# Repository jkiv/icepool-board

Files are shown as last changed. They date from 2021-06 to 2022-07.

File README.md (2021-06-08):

icepool-board
=============

KiCad 5 design files for the `icepool` project.

`icepool` is a FPGA cluster and development board.

Key features include,

- 16x headers for daughter boards.
- An FT2232H for USB communication and parallel FPGA flashing.
- One-to-many SPI interface for sending data from the PC to each daughter board.
- Daisy-chained SPI interface for passing data to and from the PC and each daughter board.
- A 6-pin ATX +12V power connector for use with conventional PC power supplies.

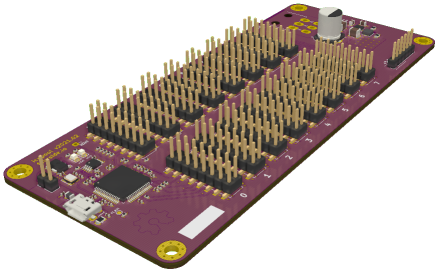
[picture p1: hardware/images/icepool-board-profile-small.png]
icepool-board - 3D Render


Currently, the project includes a daughter board design featuring a single [ice40hx8k-bg121](http://www.latticesemi.com/iCE40) FPGA with independent 1.2V LDO, 12MHz oscillator, and indicator LED.

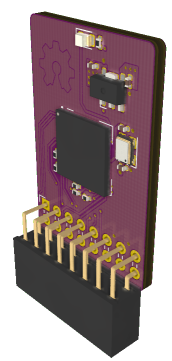
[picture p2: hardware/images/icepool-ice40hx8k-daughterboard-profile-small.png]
ice40hx8k bg121 daughter board - 3D render


## Dependencies

This project depends on the following KiCad libraries:

* [Digi-Key/digikey-kicad-library](https://github.com/Digi-Key/digikey-kicad-library)
* [jkiv/jkiv-kicad-library](https://github.com/jkiv/jkiv-kicad-library)

These repositories are set up as git submodules and can be cloned into `hardware/external/` using the following two commands:

    $ git submodule init
    $ git submodule update

## Drivers

See [jkiv/icepool-driver](https://github.com/jkiv/icepool-driver) project for a general-purpose Linux C library with Python3 bindings.

## Cores

* [jkiv/shapool-core](https://github.com/jkiv/shapool-core) - a SHA256d hashing core for cryptocurrency mining.

## Donate

Please consider supporting this project and others like it by donating:

* ☕: [ko-fi.com/jkiv_](https://ko-fi.com/jkiv_)
* ₿: `13zRrs1YDdooUN5WtfXRSDn8KnJdok4qG9`

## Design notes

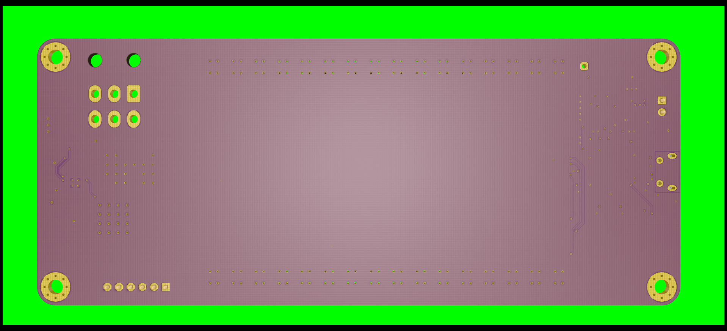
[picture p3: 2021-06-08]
hardware/images/icepool-board_bottom.png

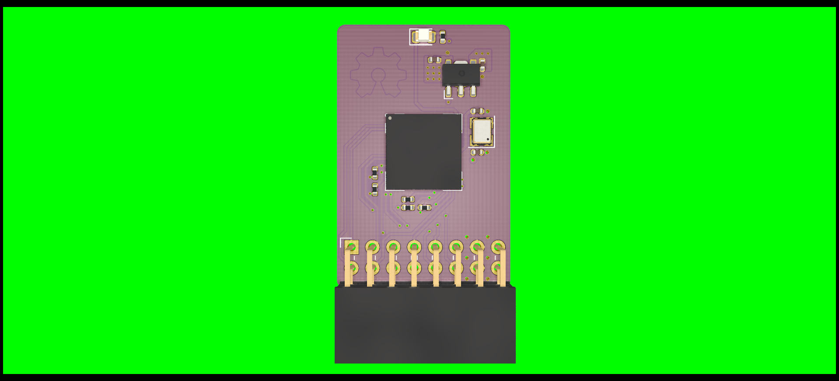
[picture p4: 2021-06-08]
hardware/images/icepool-ice40hx8k-daughterboard-top.png

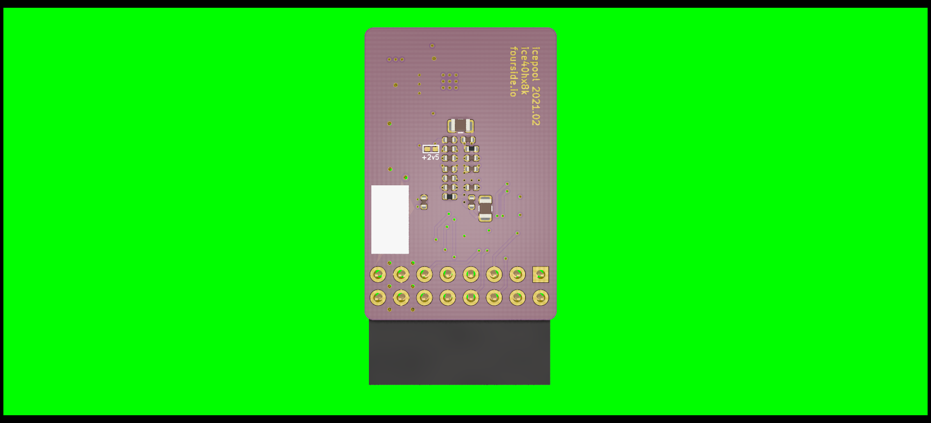
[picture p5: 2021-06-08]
hardware/images/icepool-ice40hx8k-daughterboard-bottom.png

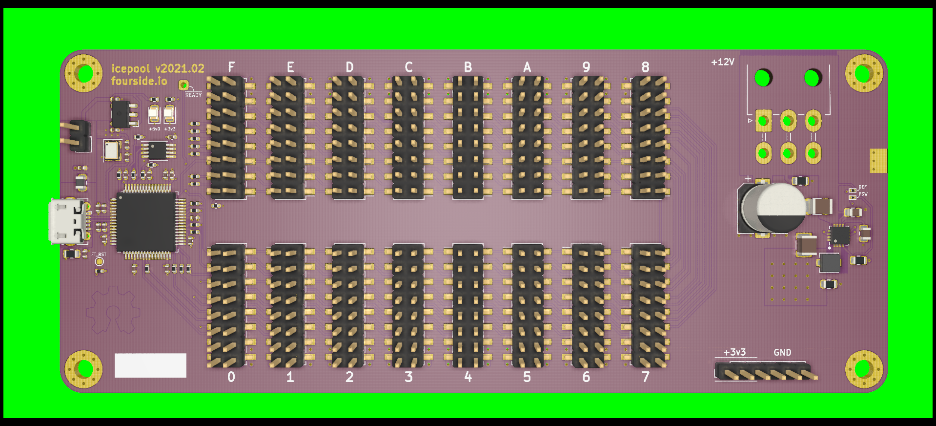
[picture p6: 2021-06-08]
hardware/images/icepool-board_top.png

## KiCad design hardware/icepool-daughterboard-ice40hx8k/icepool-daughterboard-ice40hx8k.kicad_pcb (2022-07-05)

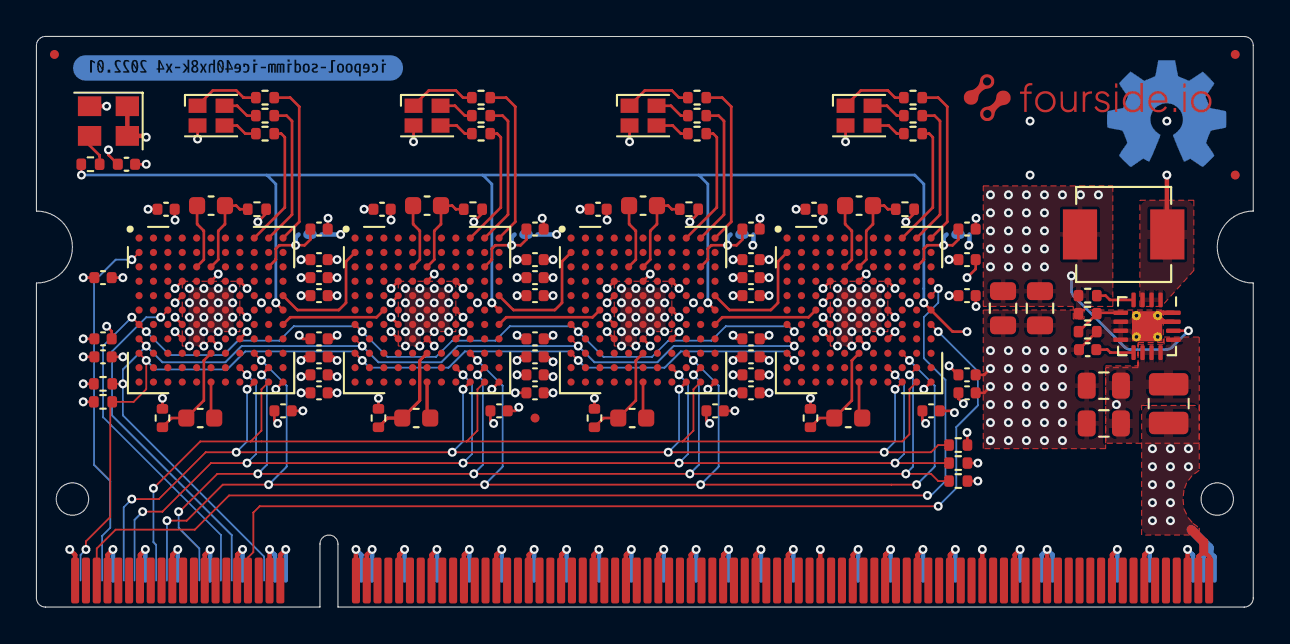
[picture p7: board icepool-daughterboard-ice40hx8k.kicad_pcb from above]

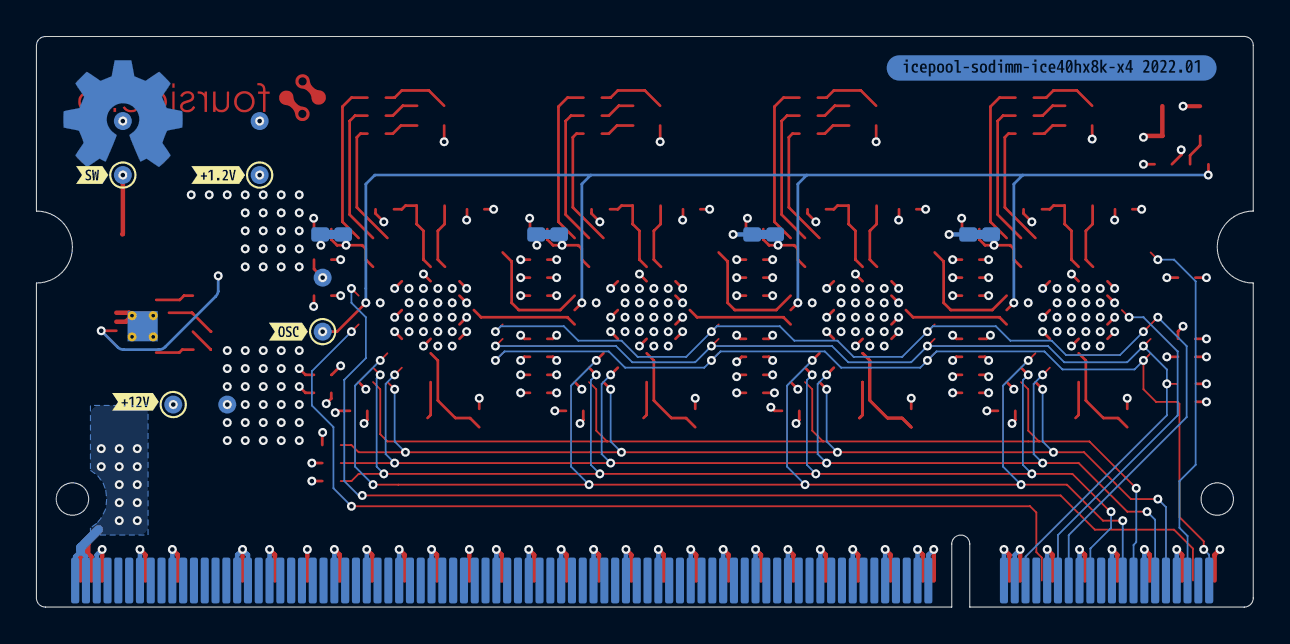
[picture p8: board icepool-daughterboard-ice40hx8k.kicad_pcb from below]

Board: 6 copper layers, 67.6 x 31.7 mm, 119 parts (19 on the bottom side), 73 nets.

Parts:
C1, C53: DNP; C_0805_2012Metric
C2, C4: 22u; C_0805_2012Metric
C3: 3.3n; C_0402_1005Metric
C5, C6, C7, C8, C9, C10, C11, C12, C14, C15, C17, C18, C19, C20, C21, C22, C23, C24, C26, C27, C29, C30, C31, C32, C33, C34, C35, C36, C38, C39, C41, C42, C43, C44, C45, C46, C47, C48, C50, C51: 0.1u; C_0402_1005Metric
C13, C16, C25, C28, C37, C40, C49, C52: 10u; C_0603_1608Metric
C54: 22u; C_0402_1005Metric
D1, D2, D3, D4: ACT_LED; LED_Cree-PLCC4_2x2mm_CW
FID1, FID2, FID3, FID4: Fiducial; Fiducial_0.5mm_Mask1mm
J1: SODIMM-200_Split; SODIMM-200-DDR2-PCB
JP1, JP2, JP3, JP4: CUT_2V5; J_Small_NC
L1: FB; L_1008_2520Metric
L2: 2.2u; L_Vishay_IHLP-2020
OSHW1: Logo_Open_Hardware_Small; OSHW-Symbol_6.7x6mm_Copper
R1: 100k; R_0402_1005Metric
R2: 75k; R_0402_1005Metric
R3: 150k; R_0402_1005Metric
R4: 22R; R_0402_1005Metric
R5, R6, R15, R16, R25, R26, R35, R36: 100R; R_0402_1005Metric
R7, R8, R10, R12, R14: 10k; R_0402_1005Metric
R9, R11, R13, R19, R21, R23, R29, R31, R33, R39, R41, R43: 1k; R_0402_1005Metric
TP1: SW_1v2; TestPoint_Pad_D1.0mm
TP2, TP4, TP6, TP8: GND; TestPoint_Pad_D1.0mm
TP3: +12V; TestPoint_Pad_D1.0mm
TP5: +1v2; TestPoint_Pad_D1.0mm
TP7: OSC_CORE; TestPoint_Pad_D1.0mm
U0, U1, U2, U3: iCE40HX8K-BG121(121-Ball_caBGA); BGA-121_11x11_9.0x9.0mm
U4: TPS62140; VQFN-16-1EP_3x3mm_P0.5mm_EP1.68x1.68mm_ThermalVias
X1: ASEM1-12.000MHZ; Oscillator_SMD_Abracon_ASE-4Pin_3.2x2.5mm
kibuzzard-62B88C8F: G***; kibuzzard-62B88C8F
kibuzzard-62B88CC0: G***; kibuzzard-62B88CC0
kibuzzard-62B88D1E: G***; kibuzzard-62B88D1E
kibuzzard-62B88D7B: G***; kibuzzard-62B88D7B
kibuzzard-62C46161: G***; kibuzzard-62C46161
kibuzzard-62C46174: G***; kibuzzard-62C46174

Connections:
12V_IN: J1.197, J1.198, J1.199, J1.200, L1.1
+1V2: C4.1, C6.2, C9.2, C11.2, C14.2, C18.2, C21.2, C23.2, C26.2, C30.2, C33.2, C35.2, C38.2, C42.2, C45.2, C47.2, C50.2, C53.1, L2.2, R1.1, R2.1, R5.2, R6.2, R15.2, R16.2, R25.2, R26.2, R35.2, R36.2, TP5.1, U0.D4 (VCC), U0.D8 (VCC), U0.H4 (VCC), U0.H8 (VCC), U1.D4 (VCC), U1.D8 (VCC), U1.H4 (VCC), U1.H8 (VCC), U2.D4 (VCC), U2.D8 (VCC), U2.H4 (VCC), U2.H8 (VCC), U3.D4 (VCC), U3.D8 (VCC), U3.H4 (VCC), U3.H8 (VCC), U4.14 (VOS)
+3V3: C5.2, C7.2, C10.2, C12.2, C15.2, C17.2, C19.2, C22.2, C24.2, C27.2, C29.2, C31.2, C34.2, C36.2, C39.2, C41.2, C43.2, C46.2, C48.2, C51.2, C54.2, D1.4 (A), D2.4 (A), D3.4 (A), D4.4 (A), J1.39, J1.40, J1.41, J1.42, JP1.1, JP2.1, JP3.1, JP4.1, R7.1, R8.1, R10.1, R12.1, U0.D6 (VCCIO_0), U0.E4 (VCCIO_3), U0.F8 (VCCIO_1), U0.G4 (VCCIO_3), U0.H6 (VCCIO_2), U0.L11 (VCC_SPI), U1.D6 (VCCIO_0), U1.E4 (VCCIO_3), U1.F8 (VCCIO_1), U1.G4 (VCCIO_3), U1.H6 (VCCIO_2), U1.L11 (VCC_SPI), U2.D6 (VCCIO_0), U2.E4 (VCCIO_3), U2.F8 (VCCIO_1), U2.G4 (VCCIO_3), U2.H6 (VCCIO_2), U2.L11 (VCC_SPI), U3.D6 (VCCIO_0), U3.E4 (VCCIO_3), U3.F8 (VCCIO_1), U3.G4 (VCCIO_3), U3.H6 (VCCIO_2), U3.L11 (VCC_SPI), X1.1 (EN), X1.4 (Vdd)
+12V: C1.2, C2.2, L1.2, TP3.1, U4.10 (AVIN), U4.11 (PVIN), U4.12 (PVIN), U4.13 (EN)
/CDONE: J1.12, R10.2, U0.K8 (CDONE), U1.K8 (CDONE), U3.K8 (CDONE)
/CRESET_B: J1.10, R7.2, U0.L9 (CRESET_B), U1.L9 (CRESET_B), U2.L9 (CRESET_B), U3.L9 (CRESET_B)
/OSC_CORE: R4.1, TP7.1, U0.F11 (GBIN3/IOR_140/PIO1_11), U1.F11 (GBIN3/IOR_140/PIO1_11), U2.F11 (GBIN3/IOR_140/PIO1_11), U3.F11 (GBIN3/IOR_140/PIO1_11)
/SCK0: J1.16, U0.L10 (SCK/IOB_107/PIO2_21), U1.L10 (SCK/IOB_107/PIO2_21), U2.L10 (SCK/IOB_107/PIO2_21), U3.L10 (SCK/IOB_107/PIO2_21)
/SCK1: J1.28, U0.G1 (GBIN6/IOL_14A/PIO3_16), U1.G1 (GBIN6/IOL_14A/PIO3_16), U2.G1 (GBIN6/IOL_14A/PIO3_16), U3.G1 (GBIN6/IOL_14A/PIO3_16)
/SDI0: J1.18, U0.J9 (SDI/IOB_106/PIO2_20), U1.J9 (SDI/IOB_106/PIO2_20), U2.J9 (SDI/IOB_106/PIO2_20), U3.J9 (SDI/IOB_106/PIO2_20)
/SDI1: J1.30, U0.F3 (GBIN7/IOL_13B/PIO3_15)
/SDO1: J1.33, U3.G11 (IOR_129/PIO1_08)
/SW_1v2: L2.1, TP1.1, U4.1 (SW), U4.2 (SW), U4.3 (SW)
/ice40-hx8k 1/GNDPLL0: C25.2, U1.L6 (GNDPLL0)
/ice40-hx8k 1/GNDPLL1: C28.2, U1.C5 (GNDPLL1)
/ice40-hx8k 1/SDI1: U0.G11 (IOR_129/PIO1_08), U1.F3 (GBIN7/IOL_13B/PIO3_15)
/ice40-hx8k 1/SDO1: U1.G11 (IOR_129/PIO1_08), U2.F3 (GBIN7/IOL_13B/PIO3_15)
/ice40-hx8k 1/VCCPLL0: C25.1, R15.1, U1.J6 (VCCPLL0)
/ice40-hx8k 1/VCCPLL1: C28.1, R16.1, U1.C6 (VCCPLL1)
/ice40-hx8k 1/VPP_2V5: C20.2, JP2.2, U1.C10 (VPP_2V5)
/ice40-hx8k 1/~ACT_B: R23.1, U1.A9 (IOT_178/PIO0_05)
/ice40-hx8k 1/~ACT_G: R21.1, U1.A10 (IOT_170/PIO0_01)
/ice40-hx8k 1/~ACT_R: R19.1, U1.A11 (IOT_168/PIO0_00)
/ice40-hx8k 1/~READY_IN: U1.E11 (IOR_148/PIO1_16), U2.B1 (IOL_2A/PIO3_00)
/ice40-hx8k 1/~READY_OUT: U0.E11 (IOR_148/PIO1_16), U1.B1 (IOL_2A/PIO3_00)
/ice40-hx8k 2/GNDPLL0: C37.2, U2.L6 (GNDPLL0)
/ice40-hx8k 2/GNDPLL1: C40.2, U2.C5 (GNDPLL1)
/ice40-hx8k 2/SDO1: U2.G11 (IOR_129/PIO1_08), U3.F3 (GBIN7/IOL_13B/PIO3_15)
/ice40-hx8k 2/VCCPLL0: C37.1, R25.1, U2.J6 (VCCPLL0)
/ice40-hx8k 2/VCCPLL1: C40.1, R26.1, U2.C6 (VCCPLL1)
/ice40-hx8k 2/VPP_2V5: C32.2, JP3.2, U2.C10 (VPP_2V5)
/ice40-hx8k 2/~ACT_B: R33.1, U2.A9 (IOT_178/PIO0_05)
/ice40-hx8k 2/~ACT_G: R31.1, U2.A10 (IOT_170/PIO0_01)
/ice40-hx8k 2/~ACT_R: R29.1, U2.A11 (IOT_168/PIO0_00)
/ice40-hx8k 2/~READY_IN: U2.E11 (IOR_148/PIO1_16), U3.B1 (IOL_2A/PIO3_00)
/ice40-hx8k 3/GNDPLL0: C49.2, U3.L6 (GNDPLL0)
/ice40-hx8k 3/GNDPLL1: C52.2, U3.C5 (GNDPLL1)
/ice40-hx8k 3/VCCPLL0: C49.1, R35.1, U3.J6 (VCCPLL0)
/ice40-hx8k 3/VCCPLL1: C52.1, R36.1, U3.C6 (VCCPLL1)
/ice40-hx8k 3/VPP_2V5: C44.2, JP4.2, U3.C10 (VPP_2V5)
/ice40-hx8k 3/~ACT_B: R43.1, U3.A9 (IOT_178/PIO0_05)
/ice40-hx8k 3/~ACT_G: R41.1, U3.A10 (IOT_170/PIO0_01)
/ice40-hx8k 3/~ACT_R: R39.1, U3.A11 (IOT_168/PIO0_00)
/ice40hx8k 0/GNDPLL0: C13.2, U0.L6 (GNDPLL0)
/ice40hx8k 0/GNDPLL1: C16.2, U0.C5 (GNDPLL1)
/ice40hx8k 0/VCCPLL0: C13.1, R5.1, U0.J6 (VCCPLL0)
/ice40hx8k 0/VCCPLL1: C16.1, R6.1, U0.C6 (VCCPLL1)
/ice40hx8k 0/VPP_2V5: C8.2, JP1.2, U0.C10 (VPP_2V5)
/ice40hx8k 0/~ACT_B: R13.1, U0.A9 (IOT_178/PIO0_05)
/ice40hx8k 0/~ACT_G: R11.1, U0.A10 (IOT_170/PIO0_01)
/ice40hx8k 0/~ACT_R: R9.1, U0.A11 (IOT_168/PIO0_00)
/~CS0: J1.24, R14.2, U0.K10 (SS/IOB_108/PIO2_22), U1.K10 (SS/IOB_108/PIO2_22), U2.K10 (SS/IOB_108/PIO2_22), U3.K10 (SS/IOB_108/PIO2_22)
/~CS1: J1.36, R12.2, U0.H1 (IOL_18A/PIO3_20), U1.H1 (IOL_18A/PIO3_20), U2.H1 (IOL_18A/PIO3_20), U3.H1 (IOL_18A/PIO3_20)
/~READY_IN: J1.5, U3.E11 (IOR_148/PIO1_16)
/~READY_OUT: J1.6, U0.B1 (IOL_2A/PIO3_00)
/~RESET: J1.2, R8.2, U0.J1 (IOL_23A/PIO3_22), U1.J1 (IOL_23A/PIO3_22), U2.J1 (IOL_23A/PIO3_22), U3.J1 (IOL_23A/PIO3_22)
GND: C1.1, C2.1, C3.2, C4.2, C5.1, C6.1, C7.1, C8.1, C9.1, C10.1, C11.1, C12.1, C14.1, C15.1, C17.1, C18.1, C19.1, C20.1, C21.1, C22.1, C23.1, C24.1, C26.1, C27.1, C29.1, C30.1, C31.1, C32.1, C33.1, C34.1, C35.1, C36.1, C38.1, C39.1, C41.1, C42.1, C43.1, C44.1, C45.1, C46.1, C47.1, C48.1, C50.1, C51.1, C53.2, C54.1, J1.1, J1.7, J1.8, J1.13, J1.14, J1.19, J1.20, J1.25, J1.26, J1.31, J1.32, J1.37, J1.38, J1.43, J1.44, J1.49, J1.50, J1.55, J1.56, J1.61, J1.62, J1.67, J1.68, J1.73, J1.74, J1.79, J1.80, J1.85, J1.86, J1.91, J1.92, J1.97, J1.98, J1.103, J1.104, J1.109, J1.110, J1.115, J1.116, J1.121, J1.122, J1.127, J1.133, J1.134, J1.139, J1.140, J1.145, J1.146, J1.151, J1.152, J1.157, J1.163, J1.164, J1.168, J1.169, J1.170, J1.181, J1.182, J1.187, J1.188, J1.195, J1.196, R3.2, R14.1, TP2.1, TP4.1, TP6.1, TP8.1, U0.E5 (GND), U0.E6 (GND), U0.E7 (GND), U0.F5 (GND), U0.F6 (GND), U0.F7 (GND), U0.G5 (GND), U0.G6 (GND), U0.G7 (GND), U0.H5 (GND), U1.E5 (GND), U1.E6 (GND), U1.E7 (GND), U1.F5 (GND), U1.F6 (GND), U1.F7 (GND), U1.G5 (GND), U1.G6 (GND), U1.G7 (GND), U1.H5 (GND), U2.E5 (GND), U2.E6 (GND), U2.E7 (GND), U2.F5 (GND), U2.F6 (GND), U2.F7 (GND), U2.G5 (GND), U2.G6 (GND), U2.G7 (GND), U2.H5 (GND), U3.E5 (GND), U3.E6 (GND), U3.E7 (GND), U3.F5 (GND), U3.F6 (GND), U3.F7 (GND), U3.G5 (GND), U3.G6 (GND), U3.G7 (GND), U3.H5 (GND), U4.6 (AGND), U4.7 (FSW), U4.8 (DEF), U4.15 (PGND), U4.16 (PGND), U4.17 (EP), X1.2 (GND)
unnamed: C3.1, U4.9 (SS/TR)
unnamed: D1.1 (RK), R9.2
unnamed: D1.2 (GK), R11.2
unnamed: D1.3 (BK), R13.2
unnamed: D2.1 (RK), R19.2
unnamed: D2.2 (GK), R21.2
unnamed: D2.3 (BK), R23.2
unnamed: D3.1 (RK), R29.2
unnamed: D3.2 (GK), R31.2
unnamed: D3.3 (BK), R33.2
unnamed: D4.1 (RK), R39.2
unnamed: D4.2 (GK), R41.2
unnamed: D4.3 (BK), R43.2
unnamed: R1.2, U4.4 (PG)
unnamed: R2.2, R3.1, U4.5 (FB)
unnamed: R4.2, X1.3 (OUT)

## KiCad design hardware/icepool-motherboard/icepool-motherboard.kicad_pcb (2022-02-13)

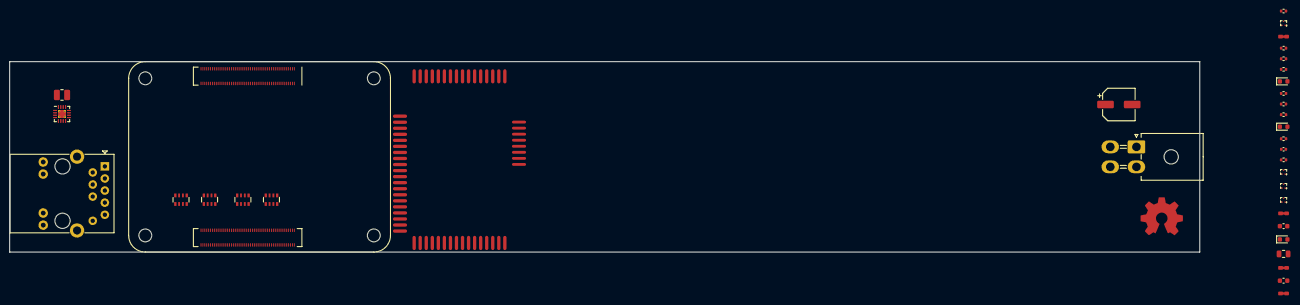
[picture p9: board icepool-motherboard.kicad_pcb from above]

Board: 2 copper layers, 250.0 x 40.0 mm, 40 parts (1 on the bottom side), 57 nets, no tracks yet.

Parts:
C1: 22u; C_0805_2012Metric
C2: 47u; CP_Elec_6.3x5.9
C3: 10u; C_0603_1608Metric
C4: 3.3n; C_0402_1005Metric
C5: 22u; C_0603_1608Metric
D1: PI_ACT; LED_0603_1608Metric
D3: 5V; LED_0603_1608Metric
D4: 3v3; LED_0603_1608Metric
D6, D7, D8, D9: TPD2EUSB30DRTR; SOT-3
J1: microSD; microSD_HC_Molex_104031-0811
J2: PWR; Molex_Mini-Fit_Jr_5569-04A2_2x02_P4.20mm_Horizontal
J3: Abracon_ARJM11-502; RJ45_Abracon_ARJP11A-MA_Horizontal
J4: S; PinHeader_1x20_P1.27mm_Vertical
J5: E; PinHeader_1x16_P1.27mm_Vertical
J6: W; PinHeader_1x16_P1.27mm_Vertical
J7: N; PinHeader_1x08_P1.27mm_Vertical
JP1, JP4: ~WL_nDisable; J_Small_NC
JP2: ~BT_nDisable; J_Small_NC
JP3: EEPROM_nWP; J_Small_NC
L2: 2.2u; L_1008_2520Metric
OSHW1: Logo_Open_Hardware_Small; OSHW-Symbol_8.9x8mm_Copper
R1, R3, R4, R8: 220R; R_0402_1005Metric
R2, R10, R11: 1k0; R_0402_1005Metric
R6: 330R; R_0402_1005Metric
R12: 100k; R_0402_1005Metric
RN1, RN2, RN3, RN4: 22R; R_Array_Convex_4x0603
U1: CM4; Raspberry-Pi-4-Compute-Module
U2: TPS62140; VQFN-16-1EP_3x3mm_P0.5mm_EP1.68x1.68mm_ThermalVias

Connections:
+1V8: U1.88, U1.90
+3V3: C1.1, D1.2, D4.2, J1.4, J3.11, J3.13, JP4.2, U1.78, U1.84, U1.86
+5V: C5.1, D3.2, L2.2, R12.1, U1.77, U1.79, U1.81, U1.83, U1.85, U1.87, U2.14
/5V_SW: L2.1, U2.1, U2.2, U2.3
/CIPO1: RN4.3, U1.26
/COPI0: RN1.3, RN3.3, U1.44
/COPI1: RN2.2, U1.27
/ETH_TD1+: D6.1, J3.1, U1.12
/ETH_TD1-: D6.2, J3.2, U1.10
/ETH_TD2+: D7.1, J3.3, U1.4
/ETH_TD2-: D7.2, J3.4, U1.6
/ETH_TD3+: D8.1, J3.7, U1.11
/ETH_TD3-: D8.2, U1.9
/ETH_TD4+: D9.1, J3.9, U1.3
/ETH_TD4-: D9.2, J3.10, U1.5
/FPGA_CDONE: J4.16, U1.46
/FPGA_CRESETB: RN2.4, U1.37
/FPGA_~READY~: J4.2, RN4.1, U1.58
/FPGA_~RESET~: RN1.4, RN3.4, U1.56
/Nodes/COPI0: J4.12, RN1.6
/Nodes/COPI1: J4.6, RN2.7
/Nodes/CRESETB: J4.18, RN2.5
/Nodes/SCK0: J4.10, RN1.8
/Nodes/SCK1: J4.4, RN2.8
/Nodes/~CS0: J4.14, RN1.7
/Nodes/~CS1: J4.8, RN2.6
/Nodes/~RESET: J4.20, RN1.5
/PI_GLOBAL_EN: R4.2, U1.99
/PI_LED_nACT: R1.2, U1.21
/SCK0: RN1.1, RN3.1, U1.38
/SCK1: RN2.1, U1.25
/SD_CLK: J1.5, U1.57
/SD_CMD: J1.3, U1.62
/SD_DAT0: J1.7, U1.63
/SD_DAT1: J1.8, U1.67
/SD_DAT2: J1.1, U1.69
/SD_DAT3: J1.2, U1.61
/~CS0: RN1.2, RN3.2, U1.39
/~CS1: RN2.3, U1.49
/~ETH_LEDL: R11.2, U1.17
/~ETH_LEDR: R10.2, U1.19
GND: C1.2, C2.2, C3.1, C4.2, C5.2, D6.3, D7.3, D8.3, D9.3, J1.6, J1.9, J4.1, J4.3, J4.5, J4.7, J4.9, J4.11, J4.13, J4.15, J4.17, J4.19, J5.1, J5.2, J5.3, J5.4, J5.5, J5.6, J5.7, J5.8, J5.9, J5.11, J5.13, J5.15, J6.1, J6.2, J6.3, J6.4, J6.5, J6.6, J6.7, J6.8, J6.9, J6.10, J6.11, J6.12, J7.2, J7.4, J7.6, J7.8, JP1.1, JP2.1, JP3.1, R2.1, R6.2, R8.2, RN3.5, RN3.6, RN3.7, RN3.8, RN4.5, RN4.6, RN4.7, RN4.8, U1.1, U1.2, U1.7, U1.8, U1.13, U1.14, U1.22, U1.23, U1.32, U1.33, U1.42, U1.43, U1.52, U1.53, U1.59, U1.60, U1.65, U1.66, U1.71, U1.74, U1.98, U1.107, U1.108, U1.113, U1.114, U1.119, U1.120, U1.125, U1.126, U1.131, U1.132, U1.137, U1.138, U1.144, U1.150, U1.155, U1.156, U1.161, U1.162, U1.167, U1.168, U1.173, U1.174, U1.179, U1.180, U1.185, U1.186, U1.191, U1.192, U1.197, U1.198, U2.5, U2.6, U2.7, U2.8, U2.15, U2.16, U2.17
unnamed: C4.1, U2.9
unnamed: D1.1, R1.1
unnamed: D3.1, R6.1
unnamed: D4.1, R8.1
unnamed: J2.1, J2.2
unnamed: J2.3, J2.4
unnamed: J3.5, J3.6
unnamed: J3.12, R11.1
unnamed: J3.14, R10.1
unnamed: JP1.2, U1.89
unnamed: JP2.2, U1.91
unnamed: JP3.2, U1.20
unnamed: JP4.1, U1.73
unnamed: R12.2, U2.4
VBUS: C2.1, C3.2, J6.13, J6.14, J6.15, J6.16, U2.10, U2.11, U2.12, U2.13

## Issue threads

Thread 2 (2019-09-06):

Add SAMD21E to schematic.

jkiv, 2019-09-06:

jkiv, 2019-09-08:
Exploring using SERCOM to implement I2C, SPI, and USART interfaces.

For the SAMD21E (32-pin):

    SERCOMx   Pins    Alt
    ----------------------
    SERCOM0  11-14    5-8
    SERCOM1  17-20   31-32
    SERCOM2  15-16   11-14
    SERCOM3  21-24   17-20
    SERCOM4    x     15-16
    SERCOM5    x     21-24

However, I2C is on pins 11 and 12, 17 and 18, and 21 and 22 only.

So how about...

* SERCOM0 - I2C (11, 12)
* SERCOM1 - SPI (17, 18, 19, 20)
* SERCOM3 - USART (21, 22, 23, 24)

Closed 2019-09-09.

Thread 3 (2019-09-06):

Add ICSP to schematic.

jkiv, 2019-09-06:

jkiv, 2019-09-08:
Using 10-pin (0.05in) "Cortex Debug" header officially.

However, also added points for connecting to Tiva C to use its in-circuit debugging interface.

Closed 2019-09-08.

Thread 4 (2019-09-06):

Add board-to-board IO to schematic.

jkiv, 2019-09-06:

jkiv, 2019-09-06:
FTDI? USB2.0? 3.0?

jkiv, 2019-09-08:
Going with USART over RS485 for now, for RS485's multi-drop support.

Using ISL83488 from Renesas to convert RS485 signal to single-ended RX and TX signals on-board.

Closed 2019-09-08.

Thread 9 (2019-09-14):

FPGA Clock Distribution

jkiv, 2019-09-14:
In the EVN-B schematic, the board appears to use a 12MHz oscillator unit with VCC, GND, STANDBY, and OUTPUT, used to drive the FTDI and FGPA chips.

Something similar to [ASV-12.000MHZ-EJ-T](https://datasheet.octopart.com/ASV-12.000MHZ-EJ-T-Abracon-datasheet-3458.pdf).

If we can't drive four FGPAs without a fan-out chip, then here's a fan-out chip that might be usable: [NB3N551](https://datasheet.octopart.com/NB3N551DG-ON-Semiconductor-datasheet-12524784.pdf).

jkiv, 2019-09-26:
Opting to forego the NB3N551 for now, unless more devices added or it is shown it's needed. Opting to use a higher load capacitance oscillator to try to drive two devices. Using a single-ended, multi-drop arrangement with a parallel termination at the end. The main clock of each FPGA doesn't need to be in sync across devices. Each device should be independent, except for data clocks.

Closed 2019-09-26.

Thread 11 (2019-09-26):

Go over hardware checklists

jkiv, 2019-09-26:
* [ICE40](http://www.latticesemi.com/-/media/LatticeSemi/Documents/ApplicationNotes/IK/iCE40HardwareChecklist.ashx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)
* [SAMD21](https://cdn.sparkfun.com/datasheets/Dev/Arduino/Boards/Atmel-42181-SAM-D21_Datasheet.pdf) pp 1008-1020

jkiv, 2019-09-28:
They were pretty minimal. Will go over layout considerations when the time comes.

Closed 2019-09-28.

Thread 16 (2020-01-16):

Rework with exposed-pin components.

jkiv, 2020-01-16:
Replace QFN components with equivalents having exposed pins to make rework easier.

jkiv, 2020-04-21:
Reflow went better with ENIG finishing and longer 240C rest time in reflow process.

Closed 2020-04-24.

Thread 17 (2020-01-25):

Add TVS to USB?

jkiv, 2020-01-25:

jkiv, 2020-06-25:
Since jkiv/kicad-breakouts has an SAMD21 breakout board, no need for superfluous IOs. Just expose bare UART if needed.

Closed 2020-06-25.

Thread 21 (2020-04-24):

Access to SPI_SS_B required for programming ice40

jkiv, 2020-04-24:
This requires major revision.

We will need to go to 48-pin MCU, _or_ use common C_RESET_B/SPI_SS_B for all devices (program at once).

For prototyping, may bodge/drive PAD 2 of pull down on SPI_SS_B.

jkiv, 2020-04-24:
Not sure why SPI_SS_B need to be set to 1 for programming. Seems like that would deselect it?

* Test whether programming works with SPI_SS_B low?
* Test whether states are swapped in guide (=1 to start, =0 during prog)?

jkiv, 2020-04-25:
Seems like we may be able to have common `CRESET_B` for all devices and separate `SPI_SS_B` for programming each.

Closed 2020-04-28.

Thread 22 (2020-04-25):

Replace ISL83485 with ISL83490

jkiv, 2020-04-25:
I can't remember why we went from ISL83490 to the ISL83485... 4-pin cable?

Either way, for some reason it seems like the x488 or the x490 would be better suited for differential-izing UART (RX+/-, TX+/-).

This affects the RPi header board as well.

jkiv, 2020-04-25:
We can keep the 4-pin cable and add a second header (IN/OUT)

Closed 2020-04-28.

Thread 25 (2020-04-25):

Get serial terminal working under Raspberry Pi

jkiv, 2020-04-25:
Get a serial terminal (UART) working under Raspberry Pi.

Currently, we're trying to use `/dev/ttyAMA0`, e.g.

    screen /dev/ttyAMA0

Ultimately, this serial terminal will be used for:

1. issuing arbitrary commands, and
1. uploading bitstream to NVM

jkiv, 2020-04-30:
I'm having an H-E-double-hockey-sticks of a time getting this to either send or receive a byte.

The main issue is that the SERCOM flags `INTFLAGS.RXC`, `INTFLAGS.TXC`, and `INTFLAGS.DRE` never set after sending or receiving a byte. There doesn't seem to be any activity on the TX line (no oscilloscope, but more on that later).

I've found some mistakes in my original code but I feel like I've weeded most of them out.

I'm not sure what causes these flags to be set. I imagine, e.g. for DRE, that the byte is shifted out, regardless of whether anyone received it.

It seems like interrupts don't need to be enabled for the `INTFLAGS` to be set (despite being called interrupt flags), so I have not enabled them.

Thinking it may be an issue with `/dev/ttyAMA0`, I decided to try an [FT232R adapter](https://www.keyestudio.com/keyestudio-ftdioriginal-chips-basic-program-downloader-usb-to-ttl-ft232usb-cable-for-arduino-p0416.html) I happen to have.

Plugging it into the RPi, it appears as `/dev/ttyUSB0`. I continued to rely on screen: `screen /dev/ttyUSB0 9600`.

Typing in the screen terminal lights the "RX" LED on the adapter. So, I focused on trying to blink the "TX" LED from the SAMD21.

Toggling the TX pin on the SAMD21 manually (as GPIO), I was able to blink the "TX" LED by connecting TX on the SAMD21 to the "RXD" pin on the 1x6 header. (Inconsistent labeling is always helpful /s)

| SAMD21 pin | SAMD21 test point | Adapter pin | Adapter LED |
| --- | --- | --- | --- |
| TX | RX | RXD | TX |
| RX | DE | TXD | RX |

After reconfiguring to send a byte-stream repeatedly, no blinking...

I then went on a tangent to test whether it was a BAUD rate issue or not (though it sounds like something else). So I tested a few things regarding baud rate:

1. I enabled async-fractional mode, and auto-baud. No luck.
1. I then switched back to async-arithmetic mode and tried to send a single byte... at every BAUD value, to see if (a) DRE would be set, or (b) I could see it on the RPi terminal. No luck.

Writing this out loud, it doesn't seem like a BAUD issue but an issue with the SERCOM being able to shift out its values -- so a clock, SERCOM, or pinmux configuration issue? 🦆

Anyway.

jkiv, 2020-05-01:
Decided to examine the state of `CTRLB.TXEN` and `CTRLB.RXEN`, which according to the datasheet should read `1` after they're enabled.

Sadly, after the USART is enabled, `while(CTRLB.TXEN == 0)` and `while(CTRLB.RXEN == 0)` both hang forever.

So, I imagine all the issues with sending and receiving have to do with the units not being enabled...

jkiv, 2020-05-17:
Ultimately an issue with UART setup on microcontroller.

Closed 2020-05-17.

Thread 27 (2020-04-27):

Replace FPGA oscillators with smaller footprint variant.

jkiv, 2020-04-27:
These footprints are huge. We can use smaller ones.

Closed 2020-04-28.

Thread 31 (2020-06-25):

Remove component labels

jkiv, 2020-06-25:
Component labels make the board, especially the backside, look busy. No real need if HTML BOM is provided.

jkiv, 2020-10-18:
Done, as of at least 6773861f.

Closed 2020-10-18.

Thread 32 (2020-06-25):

Version with 3.3V, 1.2V LDOs

jkiv, 2020-06-25:
The switch mode supply would be more efficient, but pretty pricey and parts aren't necessarily available through the usual scumbags.

1.2V 1A LDO for each pair of ice40s (500mA/ea). 3.3V 1A for IO for all devices is enough.

jkiv, 2020-10-18:
Working on "rework 202009"

jkiv, 2020-11-10:
Yeah, let's try LDO version next.

Closed 2020-11-10.

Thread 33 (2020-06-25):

Allow daisy-chain IO to be easily bypassed.

jkiv, 2020-06-25:
It'd be nice to not have to populate an entire board for testing. Solder points for bypassing the daisy-chain IO would be nice, e.g. after the second, or after the first, into the last.

jkiv, 2020-10-18:
Done, as of at least 6773861f.

Closed 2020-10-18.

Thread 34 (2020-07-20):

SPI (SERCOM1) pinout is invalid

jkiv, 2020-07-20:
SPI (SERCOM1) pinout is invalid.

Unfortunately, since these are the programming pins, they cannot be swapped on the FPGA side (i.e. in the `.pcf`).

Swapping `~WE` and `SCK` looks like the best option -- no major changes in routing and should be valid.

This requires a new board revision.

Closed 2020-10-18.

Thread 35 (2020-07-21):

Implement READY feedback

jkiv, 2020-07-21:
Devices up-stream of any positive contribution to the `READY` signal don't know about it.

Add a shared `READY_FB` signal.

jkiv, 2020-10-18:
@jkiv Not sure this is a problem, unless they're collaborating? Either way, the MCU should stop FPGAs from working if the signal makes it to the MCU. In the case of READY_ANY, it will. In the case of READY_ALL, the downstream FPGAs need to wait on the upstream FPGAs anyway.

Closed 2020-10-18.

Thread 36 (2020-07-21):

Add "ENABLE", "RUN", or "RESETish" signal

jkiv, 2020-07-21:
It'd be nice to have an explicit signal to stop work on the device.

This signal stops all work and puts the device into data read/write mode (???).

jkiv, 2020-07-21:
There should be some room to squeeze this among the GPIO/SERCOM used pins.

jkiv, 2020-07-21:
Could this possibly be the unused pin on SERCOM0, i.e. PA07?

We can test this with our breakout board.

jkiv, 2020-10-18:
Future @jkiv: more clearly, ~WE has two jobs: (1) resetting/stopping work, and (2) putting the device in a "read SPI" state. It may be wise to split the responsibility into two.

jkiv, 2021-01-24:
Not necessary at this time.

Closed 2021-01-24.

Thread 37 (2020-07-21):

`READY_0` can be a fixed value.

jkiv, 2020-07-21:
Pretty sure this is true.

jkiv, 2020-10-18:
Should be completed as of dbaf6d0. READY_0 = GND. READY_ANY is active high logic, READY_ALL is active low logic.

Closed 2020-10-18.

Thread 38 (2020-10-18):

[firmware/net] Avoid pointer aliasing and dumping bytes into buffer.

jkiv, 2020-10-18:
Currently we're loading, e.g. header structures, with raw bytes off a ringbuffer.

Instead, we may want to say,

```c
net_header_deserialize(RingBuffer* inbuf, FrameHeader* header);
```

where `net_header_deserialize` is responsible for properly reading bytes out of `inbuf` and stuffing `header`.

jkiv, 2021-01-24:
Firmware obsoleted by FTDI chip, pre-programmed flash devices.

Closed 2021-01-24.

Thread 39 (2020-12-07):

PCB Render for README

jkiv, 2020-12-07:

jkiv, 2020-12-22:
Fixed with 0055ea45

Closed 2020-12-22.

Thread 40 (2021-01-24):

USB GND Bug

jkiv, 2021-01-24:
Bug. USB shield is NC and GND pin to GND plane via RC filter. USB shield should be NC or connect to GND plane via RC filer. GND pin should go directly to GND plane. Bypassing RC filter with bodge wire should be fine in v2021.01.

jkiv, 2021-01-24:
v2021.01 - simple bodge of shorting the RC filter works. Shield is NC. Bypass RC filter means GND->GND.

Closed 2021-02-23.

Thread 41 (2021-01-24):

Smaller thermal reliefs

jkiv, 2021-01-24:
Had a tough time hand-soldering 5V breakout pins. Same probably true for 12V (haven't tried yet). Fix 'em thermals.

jkiv, 2021-02-23:
Fixed in 053f5e0b914cb774e2e764ee778fe35981c483c9

Closed 2021-02-23.

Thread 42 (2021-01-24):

Refactor 12V -> 5V buck converter

jkiv, 2021-01-24:
Buck converter is over-built. Designed for 10A @ 5V, but 10A spec is for 1.2V.

Can likely find cheaper, simpler solution for buck converter.

jkiv, 2021-01-24:
500mA x 16 @ 1.2V + 500 mA @ 3.3V ~> 2.25A @ 5V

jkiv, 2021-01-24:
More convenient packages for lower current range.

Devices worth looking at:

* BD9D320EFJ / BD9D321EFJ
* AP6503
* TPS563249

jkiv, 2021-02-23:
Using TPS62133.

Closed 2021-02-23.

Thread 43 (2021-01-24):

Swap PWR and GND planes

jkiv, 2021-01-24:
Signals on top layer, but over PWR plane. Swap GND and PWR planes to reference signals to GND plane instead.

Closed 2021-02-23.

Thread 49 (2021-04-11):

Swap 5V rail for 3.3V rail for efficiency

jkiv, 2021-04-11:
Replace [TPS62133](https://www.ti.com/product/TPS62133) (Vout=5V) for [TPS62132](https://www.ti.com/product/TPS62132) (Vout=3.3V).

Possibly replace 3.3V and 1.2V LDOs on daughter boards for "simple" 3.3->1.2V bucks?

Keep 3.3V LDO for USB power support? Move jumper to 3v3 output.

Closed 2021-04-12.

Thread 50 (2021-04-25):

Remove `icepool-power.pro`

jkiv, 2021-04-25:
KiCad loves to add project files when you open schematic files. Somehow this got committed.

jkiv, 2021-05-02:
Done with 1015cc3f...

Closed 2021-05-02.

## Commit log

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2018-06-29 Shooting for 16x for some reason.
    [ice40hx8k-bg121-board.sch, ice40hx8k-bg121.sch]
2019-09-06 Starting over with KiCad 5 and prototyping.
    [ice40hx8k-bg121-board.kicad_pcb, ice40hx8k-bg121-board.sch, ice40hx8k-bg121.sch]
2019-09-06 Created empty project for KiCad 5 version.
    [icepool-board.kicad_pcb, icepool-board.sch]
2019-09-06 Starting design. Added icepool-library.
    [icepool-board.sch]
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2019-09-07 Beginning to add MCU to schematic.
    [icepool-board.sch]
2019-09-07 Started adding FPGA sheet.
    [ice40hx8k-bg121.sch, icepool-board.sch]
2019-09-07 Much progress.
    Added FPGA, RS485, pullups, test points, etc.
    [ice40hx8k-bg121.sch, icepool-board.sch]
2019-09-09 Most of schematic laid out. Almost ready to route.
    [ice40hx8k-bg121.sch, icepool-board.sch]
2019-09-11 Associated more things with CPL parts.
    [ice40hx8k-bg121.sch, icepool-board.sch]
2019-09-16 Moved ~WE to GBIN4. Added CLK (issue #10).
    [ice40hx8k-bg121.sch, icepool-board.sch]
2019-09-16 Added oscillator module.
    Went with the smaller ASDMB but kept reference to larger
    ASV.
    Since they're small and relatively inexpensive, it might be
    worthwhile to just have one oscillator per FPGA.
    Wrong net name for OSC/CLK.
    [icepool-board.sch]
2019-09-26 Nearing schematic finalization for 2019-00
    [icepool-board.sch]
2019-09-26 Next, RJ45 board-to-board? Or checklists.
    [ice40hx8k-bg121.sch, icepool-board.sch]
2019-09-28 Went through hardware checklist (issue #11).
    [ice40hx8k-bg121.sch, icepool-board.sch]
2019-09-28 Beginning BOM, issue #12.
    [icepool-board.sch]
2019-09-28 Associated all parts, except FPGAs.
    [ice40hx8k-bg121.sch, icepool-board.sch]
2019-09-28 Added icepool-library footprint for 9x9mm BGA ca-121
    [ice40hx8k-bg121.sch]
2019-09-28 Went through DRC. Found some bugs.
    [ice40hx8k-bg121.sch, icepool-board.sch]
2019-09-28 Beginning layout.
    Briefly looked for distribution-type
    screw terminals for PWR, but opting to
    go with JST VR for now.
    [ice40hx8k-bg121.sch, icepool-board.kicad_pcb, icepool-board.sch]
2019-10-01 Playing with layout a bit more.
    [ice40hx8k-bg121.sch, icepool-board.kicad_pcb, icepool-board.sch]
2019-10-02 Placed FGPA caps and fanout.
    Switched FPGA caps to 0603. May switch everything.
    Next: set up OSC and IO buses.
    [ice40hx8k-bg121.sch, icepool-board.kicad_pcb, icepool-board.sch]
2019-10-05 Uncommitted layout progress from a while ago...
    [ice40hx8k-bg121.sch, icepool-board.kicad_pcb, icepool-board.sch]
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2019-10-07 Removed many R0s. Updated layout.
    [ice40hx8k-bg121.sch, icepool-board.kicad_pcb, icepool-board.sch]
2019-10-07 Layout done-ish. Running traces.
    Comms bus needs some breathing room... Trying at 6mil.
    [ice40hx8k-bg121.sch, icepool-board.kicad_pcb, icepool-board.sch]
2019-10-07 Reduced READY_ANY/READY_ALL to READY.
    [ice40hx8k-bg121.sch, icepool-board.kicad_pcb, icepool-board.sch]
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2019-10-10 Opting to probe exposed pins. 0.5mm too small.
    [icepool-board.kicad_pcb]
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2019-10-10 Final touches. Ran DRC. Some things need tweaking.
    [icepool-board.kicad_pcb]
2019-10-11 Took on DRC.
    Two errors remain: two vias within blonde one of 5 mil, probably OK?
    [ice40hx8k-bg121.sch, icepool-board.kicad_pcb, icepool-board.sch]
2019-10-11 Fixed missing trace on FPGA0.
    [ice40hx8k-bg121.sch, icepool-board.kicad_pcb]
2019-10-19 Softened corners. Shrunk C29/C42 by 0.1mm for DRC.
    [icepool-board.kicad_pcb]
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2019-10-21 Moderate rework.
    * Added USB.
    * Moved around SERCOMs to accommodate USB.
    * Moved power connector to another edge.
    * Updated FPGA oscillator model/footprint.
    [ice40hx8k-bg121.sch, icepool-board.kicad_pcb, icepool-board.sch]
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2019-10-29 Many updates, needs re-routing:
    * Added two ICE40HX8K's.
    * Changed ICE40 pinout to make routing more straightforward.
    * Most inputs to ICE40 are now global fabric -- why not?
    * Added CRESET_B to each FPGA, allowing for per-FPGA bitstreams.
    * Replaced LDOs with beefier ones
    * Added second +1.2V rail.
    * Replaced many passives with 0402's.
    Possible future changes:
    * New CRESET_B use the remaining pins on SAMD21, may upgrade to 48pin.
    * May add external flash or upgrade to SAMD51 for additional bitstream
    storage.
    [ice40hx8k-bg121.sch, icepool-board.kicad_pcb, icepool-board.sch]
2019-10-30 More work on layout. LDO may not cut it.
    [ice40hx8k-bg121.sch, icepool-board.kicad_pcb, icepool-board.sch]
2019-11-02 Moved icepool-board/ to hardware/ to match master *shrugs*
    [ice40hx8k-bg121.sch, icepool-board.kicad_pcb, icepool-board.sch]
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2019-11-18 Isolated F copper ground fill on power supplies.
    [ice40hx8k-bg121.sch, icepool-board.kicad_pcb, icepool-board.sch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]
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2019-11-26 SWD header is 1.27mm pitch, not 1.00mm (Oops.)
    [ice40hx8k-bg121.sch, icepool-board.kicad_pcb, icepool-board.sch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]
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2020-01-11 Updated some passive sizes. Replaced term jumper with handsolder.
    [ice40hx8k-bg121.sch, icepool-board.kicad_pcb, icepool-board.sch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]
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2020-01-23 Removed RS485. Removed pull up resistors. Added USB shield filtering.
    [ice40hx8k-bg121.sch, icepool-board.kicad_pcb, icepool-board.sch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]
2020-01-25 Minor rework.
    - Changed 5V regulator for SC70 part.
    - Added RC filter on USB shield-to-ground.
    - Placement of MCU and friends.
    - Removed all external pullup/downs except I2C.
    [ice40hx8k-bg121.sch, icepool-board.kicad_pcb, icepool-board.sch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]
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2020-01-28 Nay on RS485 for now. Chosen ISL chip for RS422. May use JST instead of RJ45.
    [ice40hx8k-bg121.sch, icepool-board.kicad_pcb, icepool-board.sch]
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2020-02-25 Added pullup/limit on reset. SWD Header TH > SMD.
    [ice40hx8k-bg121.sch, icepool-board.kicad_pcb, icepool-board.sch]
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2020-04-07 Fixed 3v3 and 1v2 buck component values.
    [icepool-board.kicad_pcb, icepool-power.sch]
2020-04-26 Changed MCU crystal to 2.5x2mm @ 16MHz. Resolves #20
    [ice40hx8k-bg121.sch, icepool-board.kicad_pcb, icepool-board.sch]
2020-04-26 Moved around RX and TX on MCU. Addresses issue #19.
    [icepool-board.sch]
2020-04-26 Added 2.54mm headers for SWD. Addresses issue #24.
    [icepool-board.sch]
2020-04-26 Added 2.54mm headers for UART. Addresses issue #23.
    [ice40hx8k-bg121.sch, icepool-board.sch]
2020-04-27 Reverted ISL83485 with ISL83488. Addresses issue #22
    [ice40hx8k-bg121.sch, icepool-board.sch]
2020-04-27 Changed CRESET_B_x to SPI_SS_B_x. Common CDONE, CRESET_B.
    Using I2C PAD[2], PAD[3] for CDONE, CRESET_B respectively.
    If not able to use them as GPIO with I2C enabled, we'll abandon I2C.
    Addresses issue #21.
    [ice40hx8k-bg121.sch, icepool-board.sch]
2020-04-28 Fixed 2V5, updated FPGA oscillators, and added indicator LEDs.
    Addresses issues #26, #27, and #28 respectively.
    [ice40hx8k-bg121.sch, icepool-board.kicad_pcb]
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2020-04-28 Updated layout. Removed fiducials.
    Completes issues #19, #20, #21, #22, #23, #24, #26, #27, and #28.
    [ice40hx8k-bg121.sch, icepool-board.kicad_pcb, icepool-board.sch]
2020-04-29 Fixed some label placements.
    [icepool-board.kicad_pcb, icepool-board.sch]
2020-09-12 Completely reworked schematic. Two FGPAs, LDOs, no SMPS, etc.
    [ice40hx8k-bg121.sch, icepool-board.sch, icepool-power.sch]
2020-09-12 Layed out passives for FGPA. Need to duplicate.
    [ice40hx8k-bg121.sch, icepool-board.kicad_pcb, icepool-board.sch]
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2020-10-18 Swapped ~WE and SCK for SERCOM1.
    DIPO = 0x3, DOPO = 0x0.
    Fixes issue #34.
    [icepool-board.sch]
2020-10-27 Continuing on rework.
    * Removed 0.05" header -- not needed for this version.
    * Ran DRC -- reworking via sizes and bus as a result.
    * In the midst of reworking VCC plane, access to +3v3.
    * Need to rework data bus.
    [icepool-board.kicad_pcb, icepool-board.sch]
2020-11-10 Simplified version with LDOs ready. Passes DRC.
    Addresses issue #32.
    [icepool-board.kicad_pcb]
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2020-11-10 Fixed line/formatting in schematic.
    [ice40hx8k-bg121.sch, icepool-board.kicad_pcb]
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2021-01-02 202009 Rework done.
    [icepool-board-B_Cu.gbr, icepool-board-B_Mask.gbr, icepool-board-B_Paste.gbr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]
2021-01-04 Progress on mother/daughter boards.
    Note for future: kicad 5.1.4 crashes when deleting "locked" vias.
    [daughter-header.sch, ft2232h.sch, ice40hx8k-bg121.sch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]
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2021-02-23 Added gerbers used in 2021-01 boards. Fixed USB GND.
    Fixed issue #40.
    [icepool-board.kicad_pcb, motherboard.sch]
2021-02-23 Swapped GND and PWR planes.
    Fixes issue #43.
    [icepool-board.kicad_pcb]
2021-02-23 Fix 3.3V and 5V on daughterboard.
    Related to issue #43.
    [icepool-board.kicad_pcb]
2021-02-23 Fixed a couple more thermal reliefs.
    Addresses issue #41.
    [icepool-board.kicad_pcb]
2021-02-23 Spread out bus signals more uniformly.
    Addresses issue #44.
    [icepool-board.kicad_pcb]
2021-02-23 +silkscreen. Version++. +OSHW
    Addresses issue #46.
    [icepool-board.kicad_pcb]
2021-02-23 Refactored for TPS62133 (5V, 3A) buck converter.
    Changes motherboard dimensions. Changes motherboard stencil.
    Addresses issue #42.
    [icepool-board.kicad_pcb, icepool-power.sch]
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2021-03-02 Replaced FT232H with FT2232H for additional SPI interface (issue #45).
    Moved +1V2 traces on daughterboard from In1 to In2 (issue #43).
    Fixed routing GND, SHIELD on USB (issue #40).
    [icepool-board.kicad_pcb, motherboard.sch]
2021-03-06 Added optional EEPROM for FT2232H (issue #47).
    Removed 2021-01 board layout files.
    Shoved motherboard headers for more space.
    Made bus lines narrower (12mil > 9mil).
    [icepool-board-daughterboard-2021-01.kicad_pcb, icepool-board-motherboard-2021-01.kicad_pcb, icepool-board.kicad_pcb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]
2021-04-12 Added daisy-chained READY for ready-all support.
    Reconfigured header pinout on motherboard and ice40hx8k daughter board.
    Addresses issue #48.
    [ice40hx8k-bg121.sch, ice40hx8k-daughter-board.sch, icepool-board.kicad_pcb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]
2021-04-12 Replaced +5V rail with +3v3 using drop-in replacement buck.
    Removed most +5V fills. +5V still available via VBUS.
    Addresses issue #49.
    [ice40hx8k-daughter-board.sch, icepool-board.kicad_pcb, icepool-power.sch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]
2021-04-21 Updated 3D models and README.
    Re-introduced M2 screw holes for daughter board.
    Also includes changes to KiCAD schematics and layout. Not sure
    exactly what changed since last commit.
    [ice40hx8k-bg121.sch, ice40hx8k-daughter-board.sch, icepool-board.kicad_pcb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]
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2021-06-08 Final tweaks for 2021-02.
    * Shrunk daughter board PCB.
    * Added ~READY[15] pulldown resistor and jumper.
    * Removed GND edge connection.
    * Added ~READY pin header.
    * Reworked daughter board signals.
    [ice40hx8k-bg121.sch, icepool-board.kicad_pcb, motherboard.sch]
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2021-08-15 More progress on CM4 blade motherboard.
    - Utilizing 40-pin 2mm "stamp" form factor.
    [ice40hx8k-bg121.sch, ice40hx8k-daughter-board.sch, icepool-power.sch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]
2021-08-18 Progress on schematic.
    - GPIO selected for FPGAs.
    - Added 1Wire temperature sensors. (Optional)
    - Added UART. (Not sure if needed.)
    - And other stuff.
    [icepool-board.sch, icepool-power.sch, motherboard.sch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]
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2021-08-20 Commit to move to Desktop to continue work.
    - Not sure about PoE if it involves flyback design. Modularize?
    - 12V from USB PD using STUSB4500 or similar, or high current 5V?
    - Not sure how to set up 12V USB PD from Pi on which it relies.
    [icepool-power.sch, motherboard.sch, node-array.sch]
2021-08-20 Progress on PoE -- using TPS23731.
    - Circuit design is a bit complex. Not sure if ideal.
    - Can fall back on MP8007, LTC4267, and possibly LT4267.
    [icepool-power.sch, motherboard.sch]
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2021-08-21 Moved motherboards and daughterboards to different project folders.
    - Added USB PD chip.
    - Removed PoE and will become daughterboard.
    - Beginning basic layout.
    [ice40hx8k-bg121.sch, icepool-board.kicad_pcb, icepool-board.sch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]
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2021-09-12 Post-stream commit.
    * Vertical daughterboards to reduce board size and complexity.
    * Flip-flopping on design choices, but meh.
    [icepool-motherboard.kicad_pcb, icepool-motherboard.sch, node-array.sch]
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2022-02-13 Yet another rework in progress.
    [icepool-daughterboard-ice40hx8k.kicad_pcb, icepool-daughterboard-ice40hx8k.sch, icepool-motherboard.kicad_pcb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]
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
